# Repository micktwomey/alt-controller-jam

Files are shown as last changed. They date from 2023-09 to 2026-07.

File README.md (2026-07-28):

# CTRL.ALT GameCraft 2023

Repo holding the hardware and code behind the controller components used in https://www.gamecraft.it/events/altctrljam-2023/

# Hardware

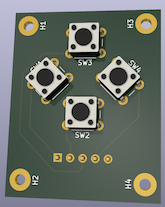
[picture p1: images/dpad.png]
Button pad hardware render


A [Raspberry Pi Pico](https://www.raspberrypi.com/products/raspberry-pi-pico/) running [CircuitPython](https://circuitpython.org/board/raspberry_pi_pico/) acts as a HID keyboard device.

Two (or more) button pads are connected to the Pico using jumper cables. Each button pad has 4 buttons.

You can position these anywhere you want on an alternative controller. Embed them in cardboard, stick onto things, etc.

[KiCad](https://www.kicad.org/) is used to design the boards. You can even see me following the tutorial in [kicad-tutorial](./kikad-tutorial/)!

[JLCPCB](https://jlcpcb.com/) was used to print the boards. Elbow grease and lots of solder was used to assemble the boards.

The schematics can be found in [dpad](./dpad/).

# Software

The Pico runs [CircuitPython](https://circuitpython.org/) and uses Adafruit's HID library to emulate a keyboard. It's also possible to emulate a mouse and a gamepad (there are some experiments for gamepad emulation in [experiments](./src/gamecraft_alt_controller_jam_board/experiments/)).

Code execution order:

1. [boot.py](./boards/circuitpython/boot.py) is run *once* on board startup to configure it. Here we enable keyboard emulation. If you change this you need to unplug and plug the board back in. If you want to pretend to be a mouse or gamepad this is where you do it.
2. Next [code.py](./boards/circuitpython/code.py) is run to configure the button mapping and listen for events. Editing this should immediately restart the code and use your changes. If you need to change the button mappings this is where you do it.

When running the library code lives in `lib` on the pico but lives in [src](./src/) here in GitHub.

- [gamecraft_alt_controller_jam_board.configurations](./src/gamecraft_alt_controller_jam_board/configurations.py) contains different example keyboard mappings you can use.
- [gamecraft_alt_controller_jam_board.hardware](./src/gamecraft_alt_controller_jam_board/hardware.py) contains mappings for pins.
- [gamecraft_alt_controller_jam_board.keyboard](./src/gamecraft_alt_controller_jam_board/keyboard.py) contains the code which acts as a keyboard, responding to GPIO pins (button clicks) and sending out keycodes.

# Building and Deploying to a Pico

[just](https://just.systems/) is used to run the build and deployment steps.

[poetry](https://python-poetry.org/) is used to manage local tool dependencies. It's also used to install libraries into your development environment, but these won't allow you to run the code on your desktop. They're primarily intended to allow for error checking.

Note that the default paths in the [justfile](./justfile) are Apple Mac defaults, you'll need to adjust them for your machine.

1. To install dependencies: `poetry install`
2. To build: `just build`
3. To flash CircuitPython onto a Pico:
    1. Hold down the `bootsel` button on the Pico while plugging in the USB cable into your machine
    2. Keep holding it down until a `RPI-RP2` disk is mounted
    3. Run `just install-firmware`
4. To deploy the built code onto the pico: `just deploy`

You can make this process a little more efficient using:

1. Run `just watch` to see which disk is mounted
2. After plugging in the pico use `just install-firmware && just deploy && just eject` in another terminal to flash the firmware and install the code in one step.

## Setting Up

If you're using [mise](https://mise.jdx.dev/) it should activate automatically.

Otherwise you need [uv](https://docs.astral.sh/uv/) and [just](https://just.systems/) installed.

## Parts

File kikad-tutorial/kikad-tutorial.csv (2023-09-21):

Source: | /Users/mick/src/github.com/codinggrace/alt-controller-jam/kikad-tutorial/kikad-tutorial.kicad_sch
Date: | 2023 September 10, Sunday 20:28:30
Tool: | Eeschema 7.0.7
Generator: | /Applications/KiCad/KiCad.app/Contents/SharedSupport/plugins/bom_csv_grouped_by_value_with_fp.py
Component Count: | 3
Ref | Qnty | Value | Cmp name | Footprint | Description | Vendor | DNP
BT1 | 1 | Battery_Cell | Battery_Cell | Battery:BatteryHolder_Bulgin_BX0036_1xC | Single-cell battery
D1 | 1 | LED | LED | LED_SMD:LED_Cree-XH | Light emitting diode
R1 | 1 | R_US | R_US | OptoDevice:R_LDR_4.9x4.2mm_P2.54mm_Vertical | Resistor, US symbol

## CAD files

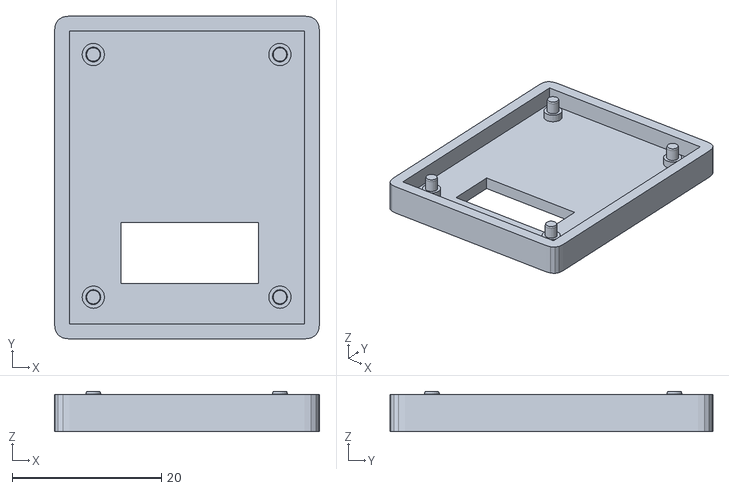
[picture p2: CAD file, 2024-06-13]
dpad/Alt controller case.stl
35.5 x 43.2 x 5.40

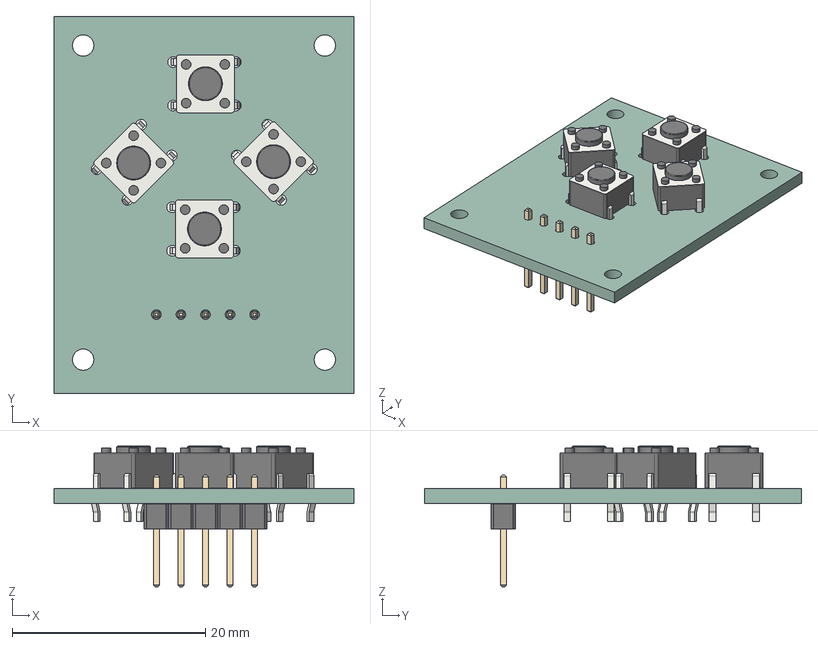
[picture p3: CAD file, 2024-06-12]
dpad/dpad.step
31.0 x 39.0 x 14.5 mm
dpad PCB

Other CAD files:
dpad/dpad.stl

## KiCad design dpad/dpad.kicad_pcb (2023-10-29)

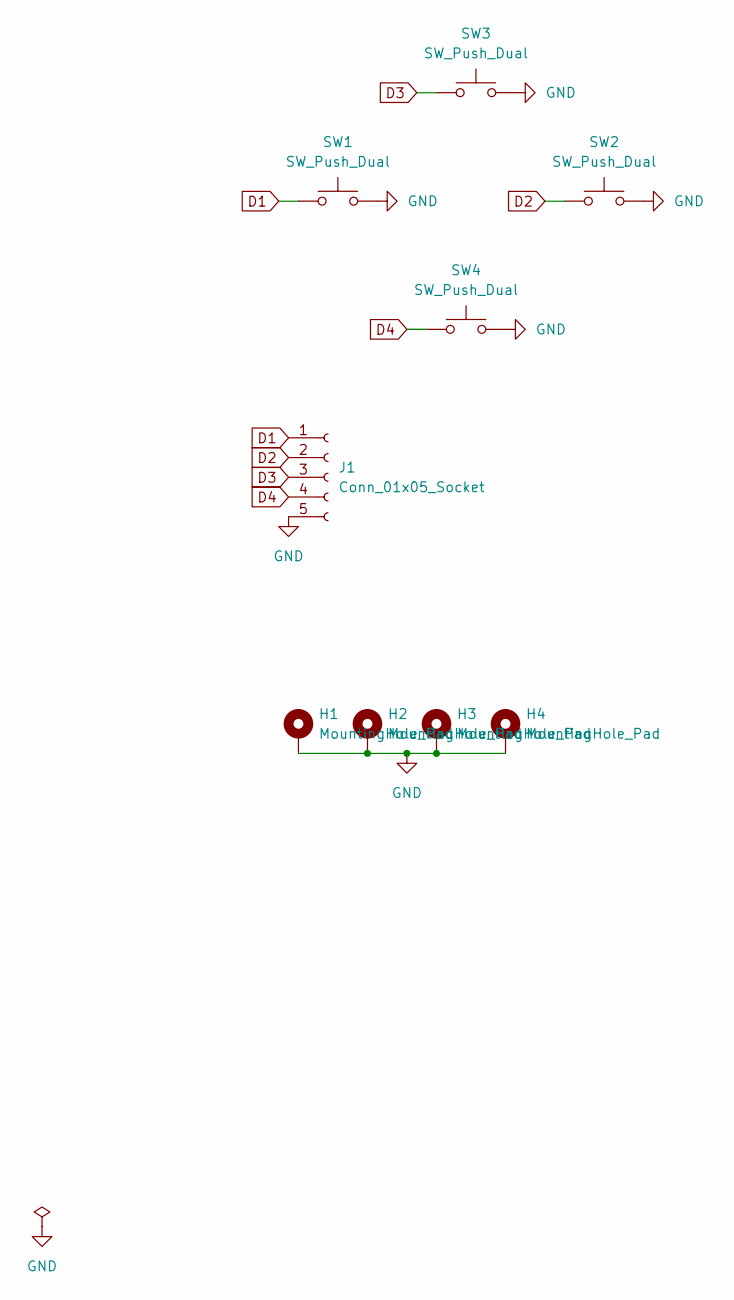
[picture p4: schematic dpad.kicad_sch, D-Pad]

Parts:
H1, H2, H3, H4: MountingHole_Pad; MountingHole_2.2mm_M2_Pad
J1: Conn_01x05_Socket; PinHeader_1x05_P2.54mm_Vertical
SW1, SW2, SW3, SW4: SW_Push_Dual; SW_PUSH_6mm

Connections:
D1: J1.1, SW1.1
D2: J1.2, SW2.1
D3: J1.3, SW3.1
D4: J1.4, SW4.1
GND: H1.1, H2.1, H3.1, H4.1, J1.5, SW1.2, SW2.2, SW3.2, SW4.2

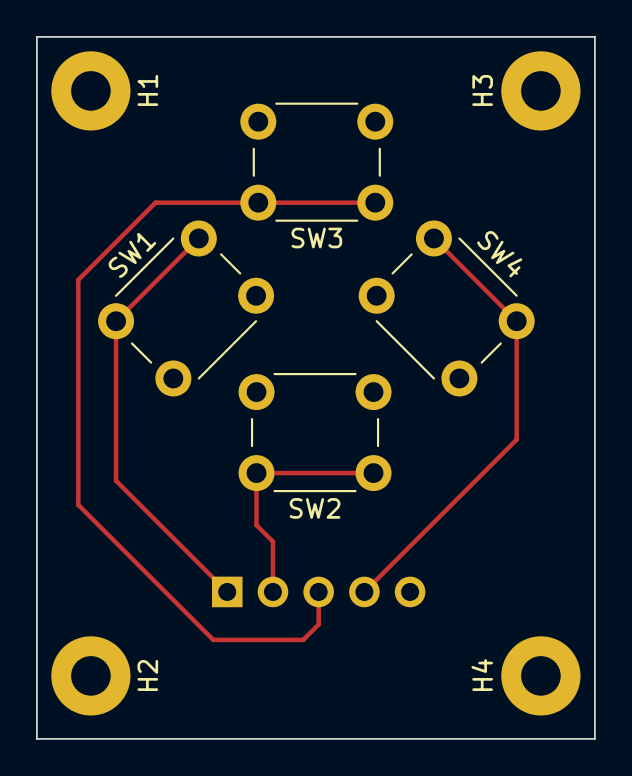
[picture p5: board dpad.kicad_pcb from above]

Board: 2 copper layers, 31.0 x 39.0 mm, 9 parts (1 on the bottom side), 5 nets.

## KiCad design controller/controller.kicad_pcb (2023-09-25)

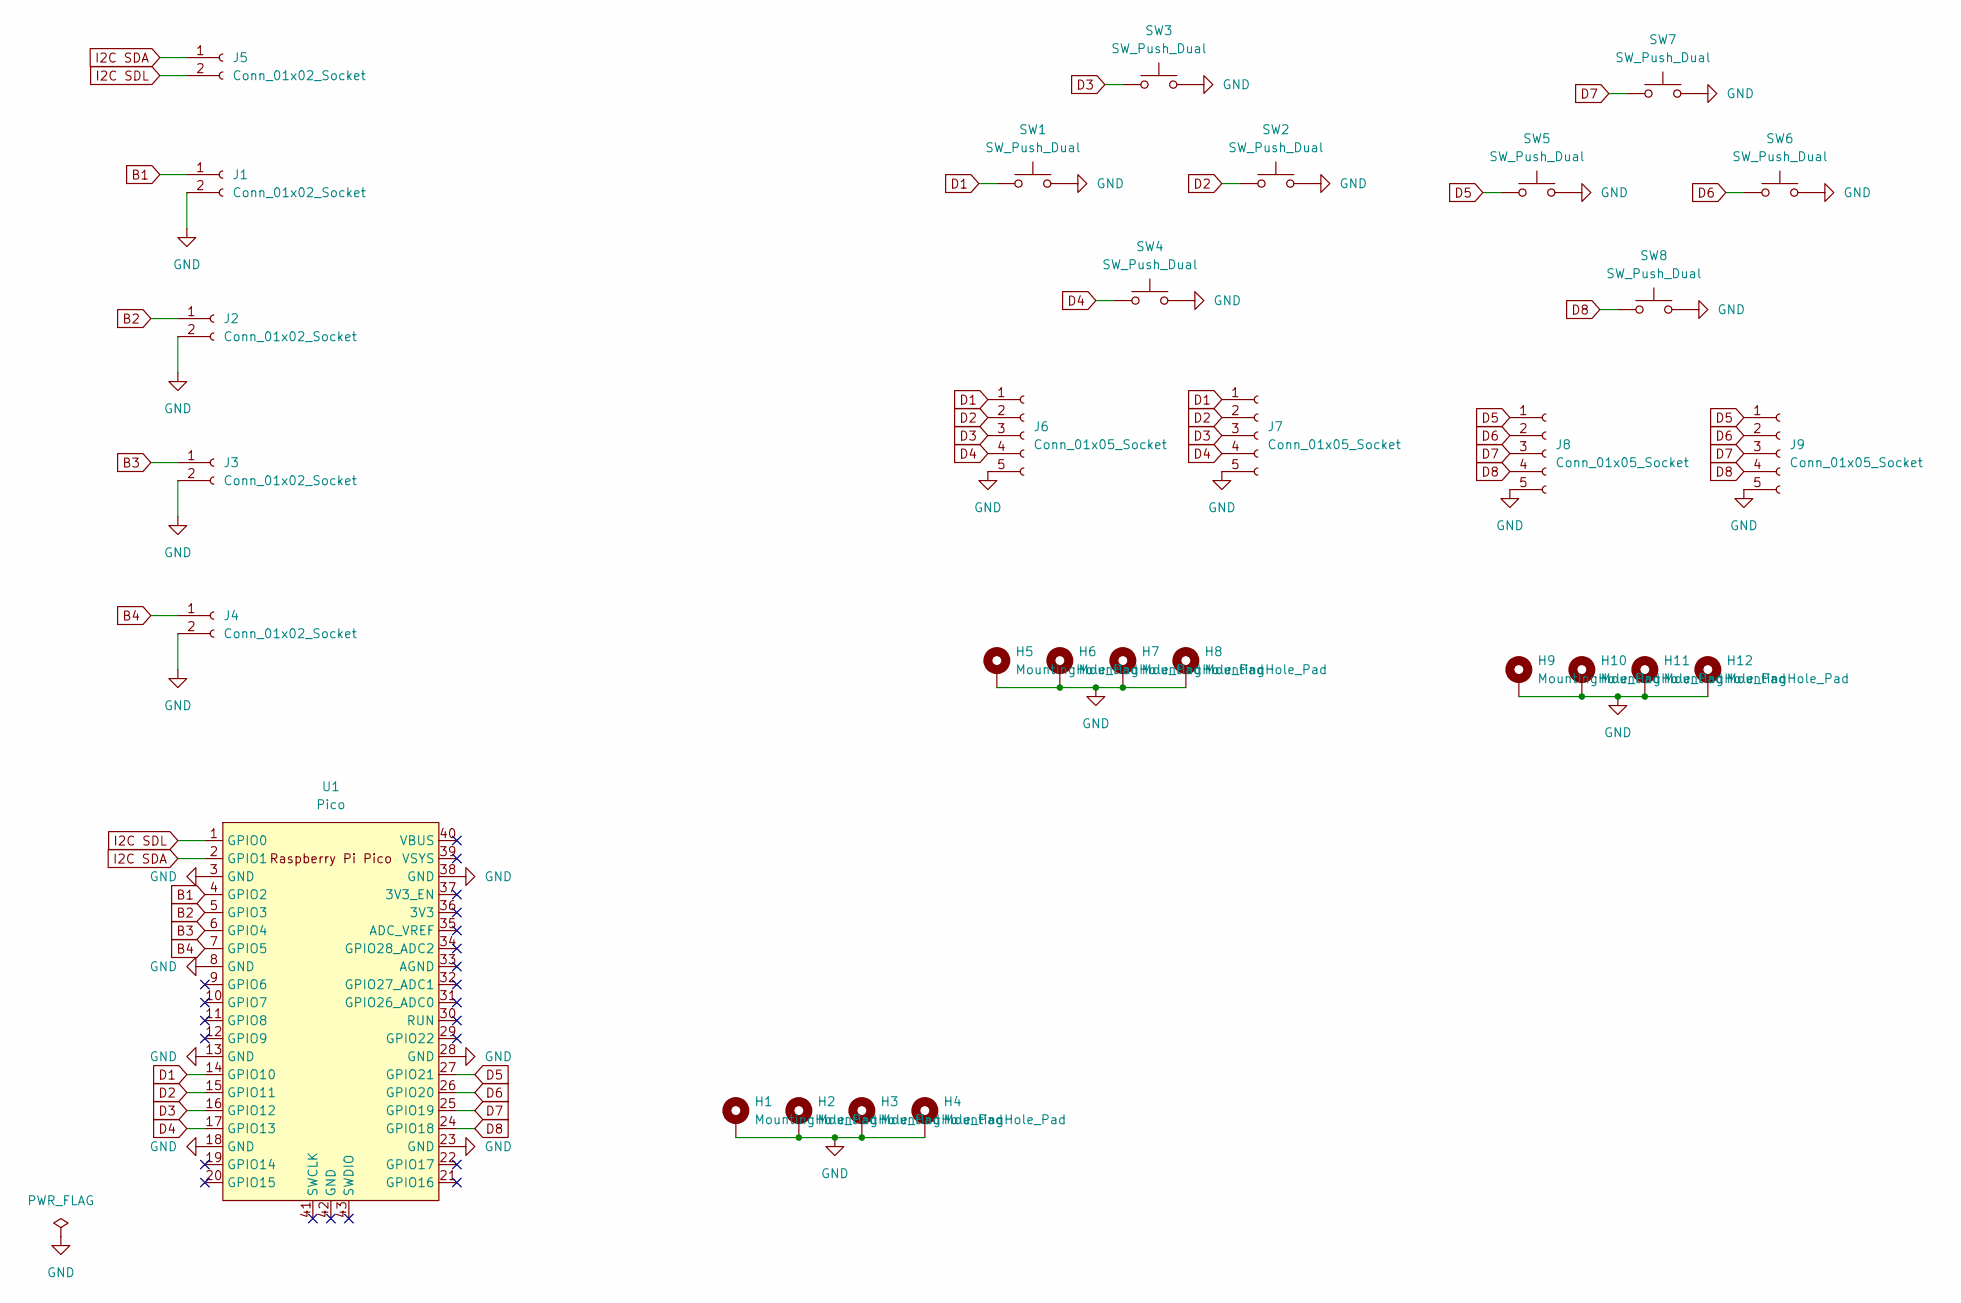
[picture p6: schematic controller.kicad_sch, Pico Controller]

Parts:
H1, H2, H3, H4, H5, H6, H7, H8, H9, H10, H11, H12: MountingHole_Pad; MountingHole_3.2mm_M3_Pad
J1, J2, J3, J4, J5: Conn_01x02_Socket; JST_XH_B2B-XH-AM_1x02_P2.50mm_Vertical
J6, J7, J8, J9: Conn_01x05_Socket; PinHeader_1x05_P1.00mm_Vertical
SW1, SW2, SW3, SW4, SW5, SW6, SW7, SW8: SW_Push_Dual; SW_PUSH-12mm
U1: Pico; RPi_Pico_SMD_TH

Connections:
B1: J1.1, U1.4 (GPIO2)
B2: J2.1, U1.5 (GPIO3)
B3: J3.1, U1.6 (GPIO4)
B4: J4.1, U1.7 (GPIO5)
D1: J6.1, J7.1, SW1.1, U1.14 (GPIO10)
D2: J6.2, J7.2, SW2.1, U1.15 (GPIO11)
D3: J6.3, J7.3, SW3.1, U1.16 (GPIO12)
D4: J6.4, J7.4, SW4.1, U1.17 (GPIO13)
D5: J8.1, J9.1, SW5.1, U1.27 (GPIO21)
D6: J8.2, J9.2, SW6.1, U1.26 (GPIO20)
D7: J8.3, J9.3, SW7.1, U1.25 (GPIO19)
D8: J8.4, J9.4, SW8.1, U1.24 (GPIO18)
GND: H1.1, H2.1, H3.1, H4.1, H5.1, H6.1, H7.1, H8.1, H9.1, H10.1, H11.1, H12.1, J1.2, J2.2, J3.2, J4.2, J6.5, J7.5, J8.5, J9.5, SW1.2, SW2.2, SW3.2, SW4.2, SW5.2, SW6.2, SW7.2, SW8.2, U1.3 (GND), U1.8 (GND), U1.13 (GND), U1.18 (GND), U1.23 (GND), U1.28 (GND), U1.38 (GND)
I2C SDA: J5.1, U1.2 (GPIO1)
I2C SDL: J5.2, U1.1 (GPIO0)

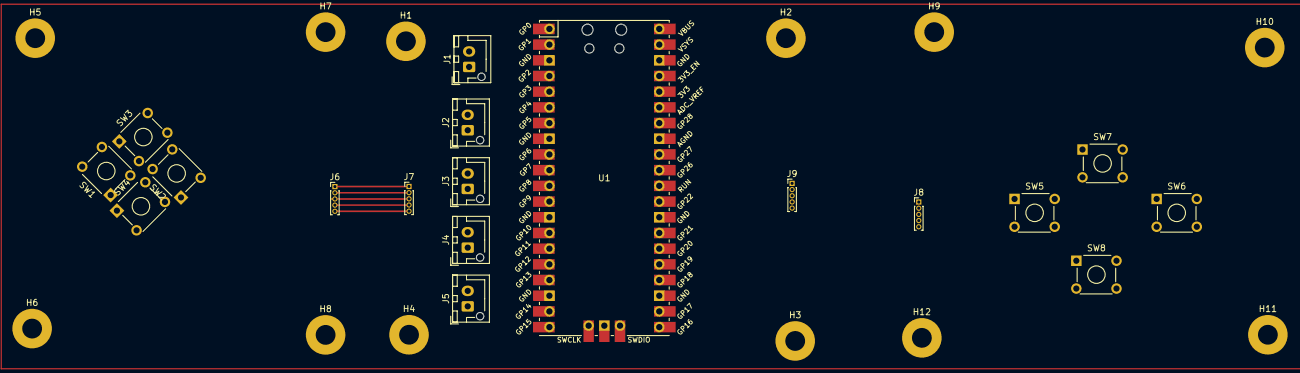
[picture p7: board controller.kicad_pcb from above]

Board: 2 copper layers, 30 parts (0 on the bottom side), 15 nets.

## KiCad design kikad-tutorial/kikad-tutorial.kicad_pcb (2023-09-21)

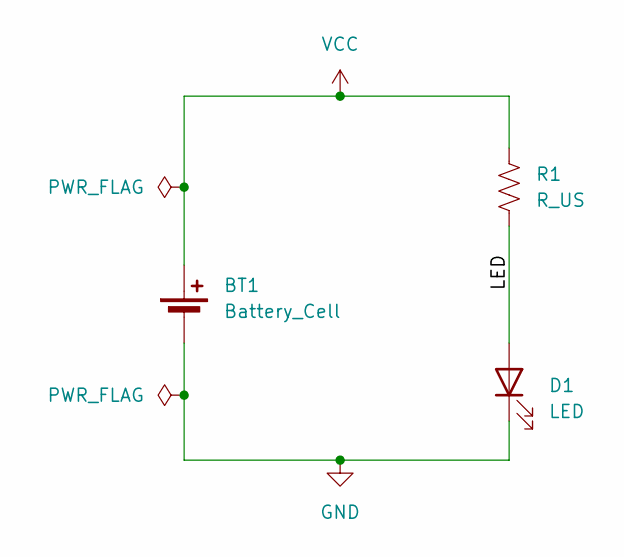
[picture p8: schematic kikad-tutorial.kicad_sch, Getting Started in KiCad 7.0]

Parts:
BT1: Battery_Cell; BatteryHolder_Keystone_1058_1x2032
D1: LED; LED_D5.0mm
R1: R_US; R_Axial_DIN0309_L9.0mm_D3.2mm_P12.70mm_Horizontal

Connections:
/LED: D1.2 (A), R1.2
GND: BT1.2 (-), D1.1 (K)
VCC: BT1.1 (+), R1.1

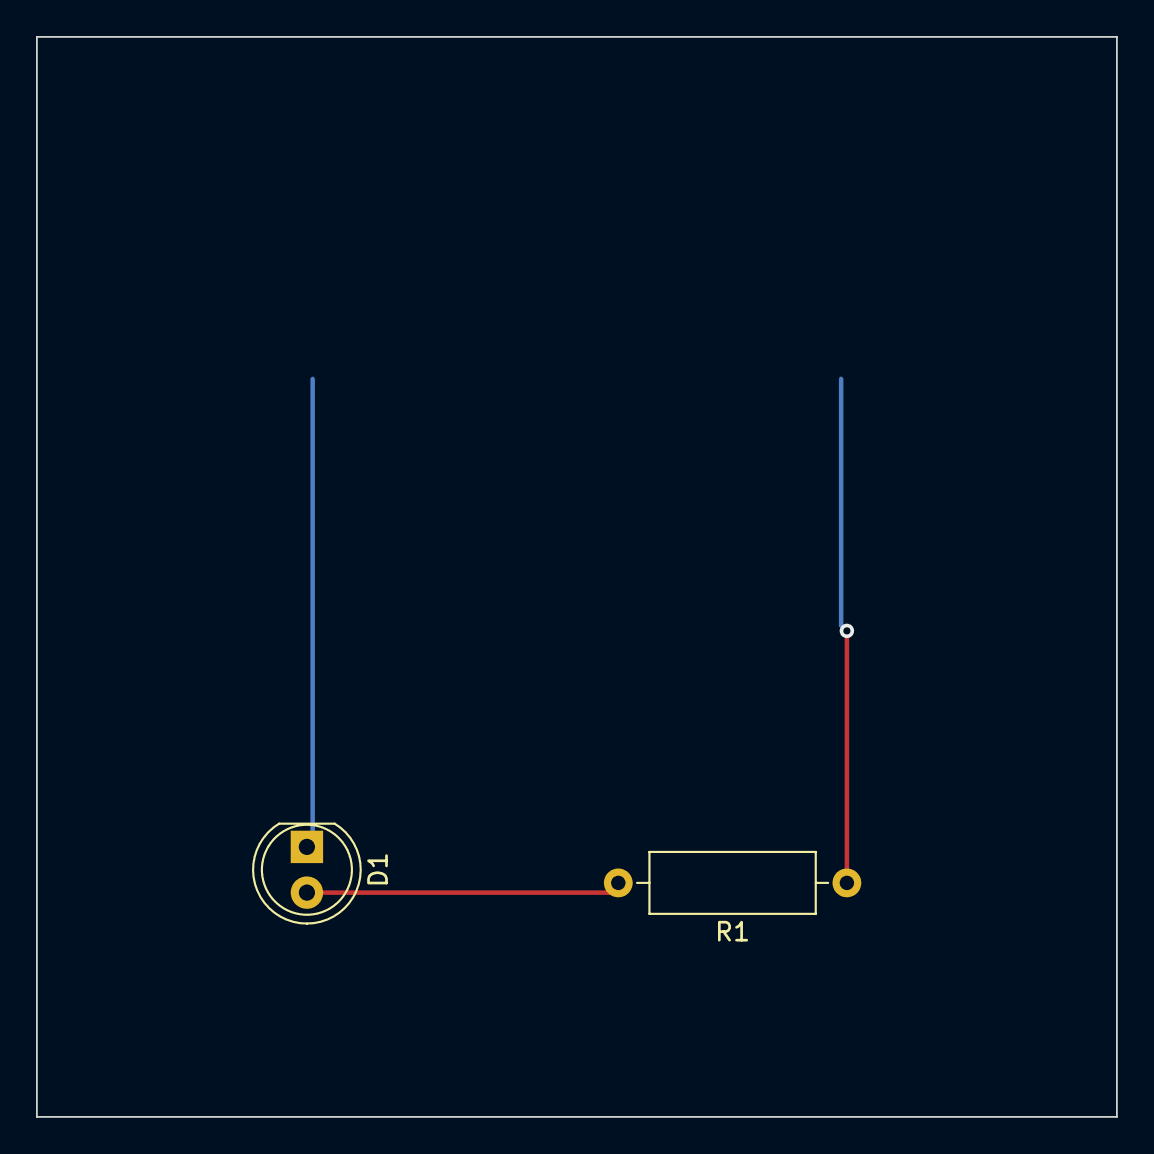
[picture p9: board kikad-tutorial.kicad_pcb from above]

Board: 2 copper layers, 60.0 x 60.0 mm, 3 parts (1 on the bottom side), 3 nets.

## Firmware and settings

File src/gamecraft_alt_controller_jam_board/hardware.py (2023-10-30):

"""Alt-Controller-Jam Controller Hardware
"""

import board


class Board:
    """Hardware boards

    Layout (facing the board from the button side):

        Header Pins
        |o|o|o|o|o|

            SW2
            O
        SW4 O   O SW1
            O
            SW3

    On bottom:

        Header Pins
        |SW1 |SW2 |SW3 |SW4 |GND|
        |GP5 |GP4 |GP3 |GP2 |GND|
        |GP9 |GP8 |GP7 |GP6 |GND|
        |GP13|GP12|GP11|GP10|GND|
        |GP18|GP19|GP20|GP21|GND|

    Header pins are grouped by matching sets on the pico
    """

    TOP = [board.GP4, board.GP8, board.GP12, board.GP19]  # SW2
    BOTTOM = [board.GP3, board.GP7, board.GP11, board.GP20]  # SW3
    LEFT = [board.GP2, board.GP6, board.GP10, board.GP21]  # SW5
    RIGHT = [board.GP5, board.GP9, board.GP13, board.GP18]  # SW1


class FirstBoard:
    TOP = Board.TOP[0]  # SW2
    BOTTOM = Board.BOTTOM[0]  # SW3
    LEFT = Board.LEFT[0]  # SW4
    RIGHT = Board.RIGHT[0]  # SW1


class SecondBoard:
    TOP = Board.TOP[1]  # SW2
    BOTTOM = Board.BOTTOM[1]  # SW3
    LEFT = Board.LEFT[1]  # SW4
    RIGHT = Board.RIGHT[1]  # SW1


class ThirdBoard:
    TOP = Board.TOP[2]  # SW2
    BOTTOM = Board.BOTTOM[2]  # SW3
    LEFT = Board.LEFT[2]  # SW4
    RIGHT = Board.RIGHT[2]  # SW1


class FourthBoard:
    TOP = Board.TOP[3]  # SW2
    BOTTOM = Board.BOTTOM[3]  # SW3
    LEFT = Board.LEFT[3]  # SW4
    RIGHT = Board.RIGHT[3]  # SW1


class DPad:
    """Directional Pad

           UP
           O
    LEFT O   O RIGHT
           O
          DOWN
    """

    UP = FirstBoard.TOP
    DOWN = FirstBoard.BOTTOM
    LEFT = FirstBoard.LEFT
    RIGHT = FirstBoard.RIGHT


class NintendoButtons:
    """Nintendo

        X
        O
    Y O   O A
        O
        B
    """

    A = ThirdBoard.RIGHT
    B = ThirdBoard.BOTTOM
    X = ThirdBoard.TOP
    Y = ThirdBoard.LEFT


class SteamButtons:
    """Steam / Xbox / Windows

        Y
        O
    X O   O B
        O
        A
    """

    A = ThirdBoard.BOTTOM
    B = ThirdBoard.RIGHT
    X = ThirdBoard.LEFT
    Y = ThirdBoard.TOP

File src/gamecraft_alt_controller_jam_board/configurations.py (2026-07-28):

"""Configurations for different styles of keyboard controllers

"""

from adafruit_hid.keycode import Keycode
from gamecraft_alt_controller_jam_board import hardware

# Pico-8 controller layout, player 1
PICO_8_PLAYER_1 = {
    hardware.DPad.UP: Keycode.UP_ARROW,
    hardware.DPad.DOWN: Keycode.DOWN_ARROW,
    hardware.DPad.LEFT: Keycode.LEFT_ARROW,
    hardware.DPad.RIGHT: Keycode.RIGHT_ARROW,
    hardware.SteamButtons.A: Keycode.X,
    hardware.SteamButtons.B: Keycode.Z,
    hardware.SteamButtons.X: Keycode.X,
    hardware.SteamButtons.Y: Keycode.Z,
}

# Pico-8 controller layout, player 2
PICO_8_PLAYER_2 = {
    hardware.DPad.UP: Keycode.E,
    hardware.DPad.DOWN: Keycode.D,
    hardware.DPad.LEFT: Keycode.S,
    hardware.DPad.RIGHT: Keycode.F,
    hardware.SteamButtons.A: Keycode.Q,
    hardware.SteamButtons.B: Keycode.TAB,
    hardware.SteamButtons.X: Keycode.Q,
    hardware.SteamButtons.Y: Keycode.TAB,
}

# Nintendo controller layout
NINTENDO = {
    hardware.DPad.UP: Keycode.UP_ARROW,
    hardware.DPad.DOWN: Keycode.DOWN_ARROW,
    hardware.DPad.LEFT: Keycode.LEFT_ARROW,
    hardware.DPad.RIGHT: Keycode.RIGHT_ARROW,
    hardware.NintendoButtons.A: Keycode.A,
    hardware.NintendoButtons.B: Keycode.B,
    hardware.NintendoButtons.X: Keycode.X,
    hardware.NintendoButtons.Y: Keycode.Y,
}

# Steam controller layout
STEAM = {
    hardware.DPad.UP: Keycode.UP_ARROW,
    hardware.DPad.DOWN: Keycode.DOWN_ARROW,
    hardware.DPad.LEFT: Keycode.LEFT_ARROW,
    hardware.DPad.RIGHT: Keycode.RIGHT_ARROW,
    hardware.SteamButtons.A: Keycode.S,
    hardware.SteamButtons.B: Keycode.D,
    hardware.SteamButtons.X: Keycode.A,
    hardware.SteamButtons.Y: Keycode.W,
}

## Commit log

2023-09-21 WIP: starting on controller
    [controller.kicad_pcb, controller.kicad_sch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]
2023-09-25 Splitting dpad out into its own board
    [controller.kicad_pcb, controller.kicad_sch, dpad.kicad_pcb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]
2023-09-26 dpad v0
    [dpad.kicad_pcb, dpad.kicad_sch]
2023-10-29 dpad v1
    [dpad.kicad_pcb, dpad.kicad_sch]
2023-10-30 Initial HID controller using circuitpython
    Using circuitpython to act as a HID keyboard.
    Also explored acting as a gamepad but this likely requires more configuration to map buttons.
2023-10-30 Create keyboard input controller and sample configurations
    Should be easy enough to customize or switch configurations.
    Focussing on keyboard only for now.
2023-10-30 Add just install-circuitpython action to download and install circuitpython
2023-11-01 Add more actions to justfile
    Can now flash firmware, copy code and eject in one: `just install-firmware && just deploy && just eject`
    Add `just watch` so you can see the state of the connected device
2024-06-12 Creating initial case in Tinkercad
    [dpad.step, dpad.stl]
2024-06-13 Next version of case
    [Alt controller case.stl]
2024-06-13 Minor tweak to case
    [Alt controller case.stl]
2024-06-14 Add a 20x 3D print job
2024-06-14 Add fab outputs
    [dpad-B_Cu.gbr, dpad-B_Mask.gbr, dpad-B_Paste.gbr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]
2026-07-28 Revamp project as installable pypi package
    Install via gamecraft-alt-controller-jam-board
    [configurations.py, hardware.py, hid_gamepad.py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]
